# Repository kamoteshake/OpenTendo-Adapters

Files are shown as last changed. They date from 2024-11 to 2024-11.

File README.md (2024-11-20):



# OpenTendo-Adapters
Some components of OpenTendo are already obsolete or NRND (Not Recommended for New Design). OpenTendo-Adapters is trying to solve this issue by using a modern equivalent of the OpenTendo components with different footprints and adapting it OpenTendo.

> [!NOTE]
> If for some reason you can't find the components listed in the BOMs and/or decided to find your own, I recommend looking at the `Datasheets` folder. I've included the datasheets of the components used in OEM NES. Look for components that are close to the original component from OEM NES spec wise and that fits on the footprint in the adapters (or you could always fork this and update your own adapter 😉).

## File Structure
```
.
├── <Reference> Adapter  # Contains all files for a specific adapter.
|   |                      "Reference" is based from OpenTendo (i.e. X2 Adapter).
|   ├── BOM              # Contains the bill of materials.
|   ├── Datasheets       # Contains the datasheets of component/s used in the OEM NES
|   |                      on the referenced footprint of OpenTendo.
|   ├── Gerber Files     # Contains The gerber files needed for fabrication.
|   └── KiCad            # Contains all files necessary to open the project in KiCad. 
```

## License
Licensed under the TAPR Open Hardware License ([www.tapr.org/OHL](www.tapr.org/OHL))

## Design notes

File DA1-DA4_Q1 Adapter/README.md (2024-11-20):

# DA1-DA4 Q1 Adapter
DAN601 and uPA64H have been obsolete for a while. It's been difficult to find diode arrays that are close to DAN601 and uPA64H specs wise. It is easier to build an array from multiple single diodes. Since 2SA937 (Q1 in OpenTendo) is close by the diode arrays and is also obsolete, I decided to just include it in this adapter with a newer component that is somewhat close to 2SA937 spec wise.

## Gerber Files
There are two files in [Gerber Files](./Gerber%20Files/):
1. Single Board - Only consist of just one board.
2. Panelized - Consist of multiple board to fit in a 100mm x 100mm board. The panel have 9 (3x3) adapters. It is panelized using mouse bites.

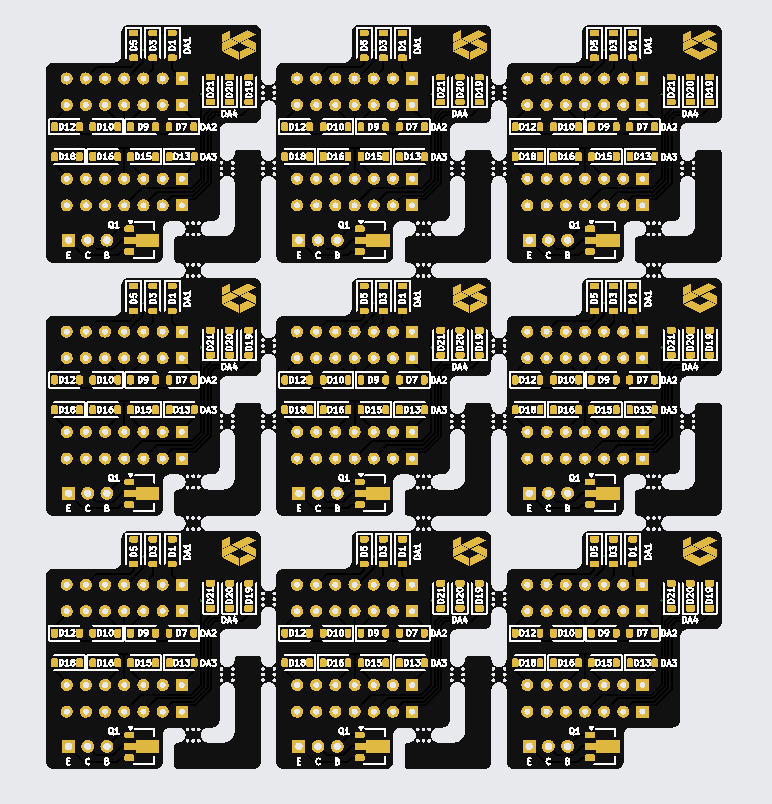
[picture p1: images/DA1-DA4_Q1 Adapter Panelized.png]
Panelized


## Assembly Tips
When soldering the pins, to make sure everything is lined up, put the pin through OpenTendo then put the adapter on the pins and tack some of the header pins before pulling it off from the OpenTendo. You can then finish soldering the pins on the adapter then you can solder the adapter to the OpenTendo.

## Images
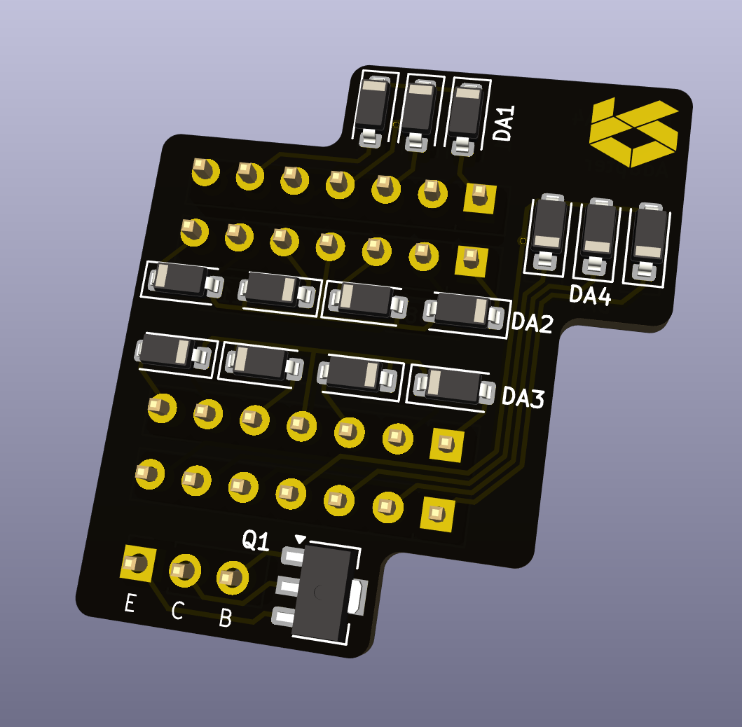
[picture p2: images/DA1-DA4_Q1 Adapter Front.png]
Front

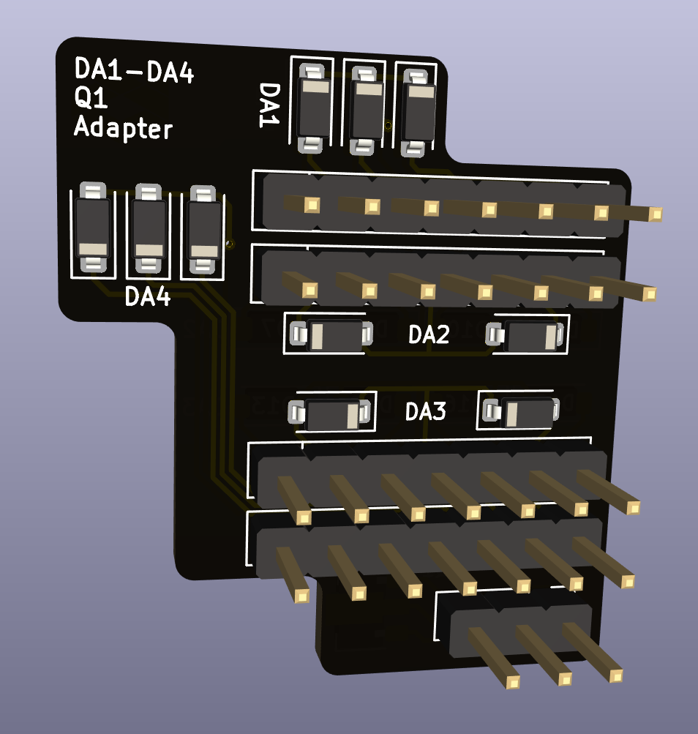
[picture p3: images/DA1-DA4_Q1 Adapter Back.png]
Back

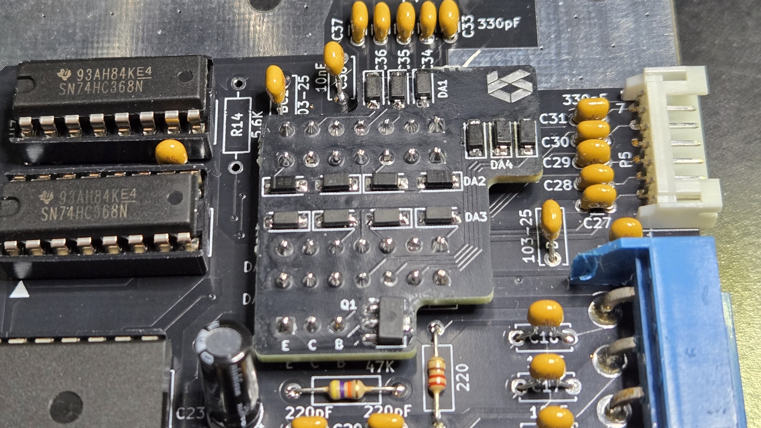
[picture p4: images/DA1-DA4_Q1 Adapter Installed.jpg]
Installed


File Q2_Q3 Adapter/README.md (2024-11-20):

# Q2 Q3 Adapter
This adapter replaces the 2SC2021 transistors. This transistor is used for the clock circuit. You might have to adjust the cap trimmer (TC1 in OpenTendo) to get a stable clock (21.47727MHz for NTSC and 26.601712MHz for PAL).

## Gerber Files
There are two files in [Gerber Files](./Gerber%20Files/):
1. Single Board - Only consist of just one board.
2. Panelized - Consist of multiple board to fit in a 100mm x 100mm board. The panel have 90 (10x9) adapters. It is panelized using mouse bites.

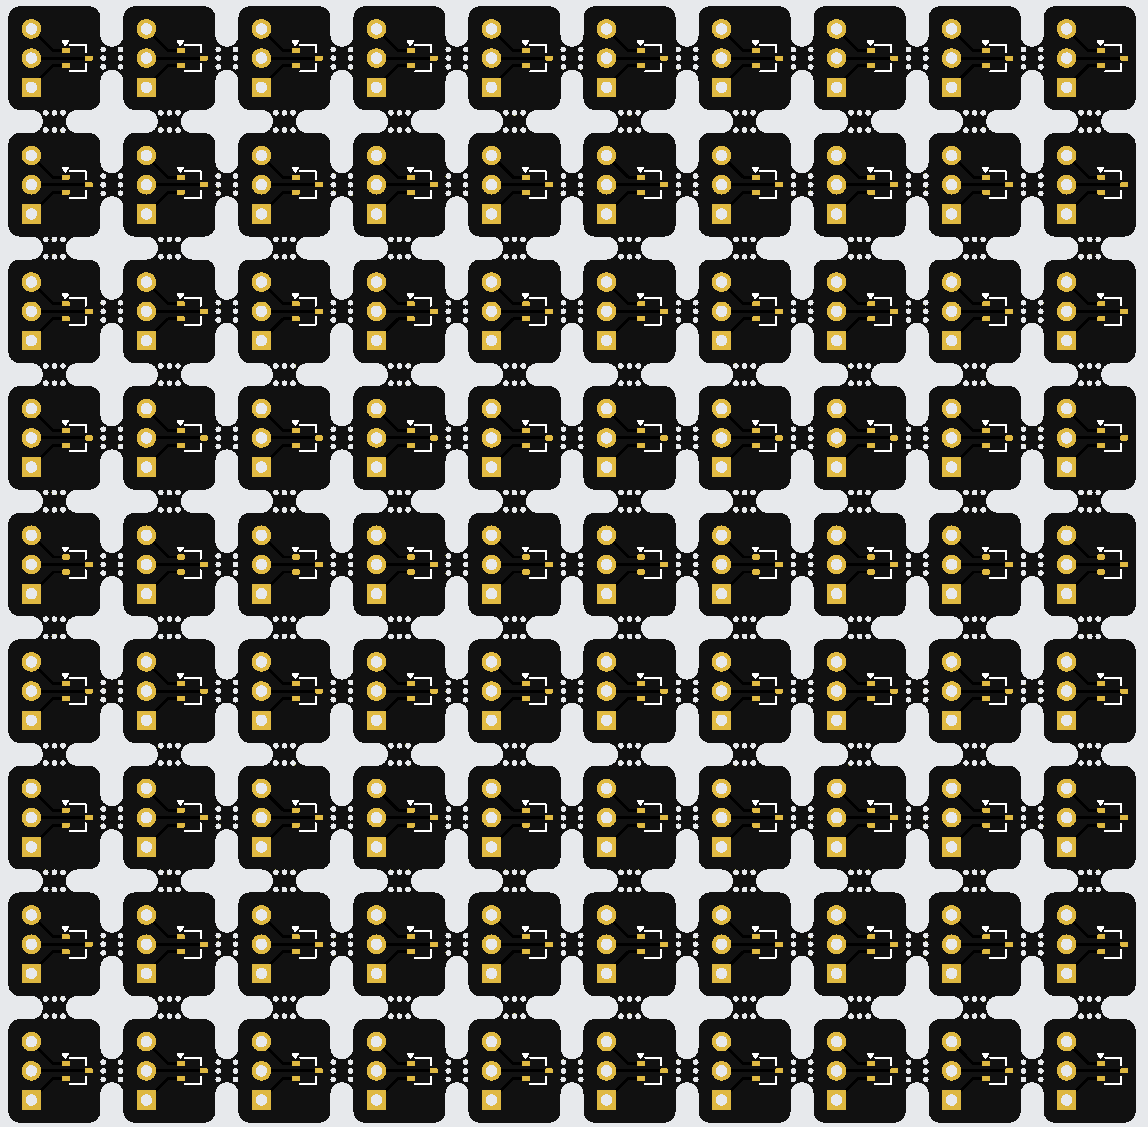
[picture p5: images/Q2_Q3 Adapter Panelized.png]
Panelized


## Assembly Tips
If you're using the right angle header pins, put the longer pins on the adapter side so you save a tiny bit of vertical space then you can just trim the pins off.

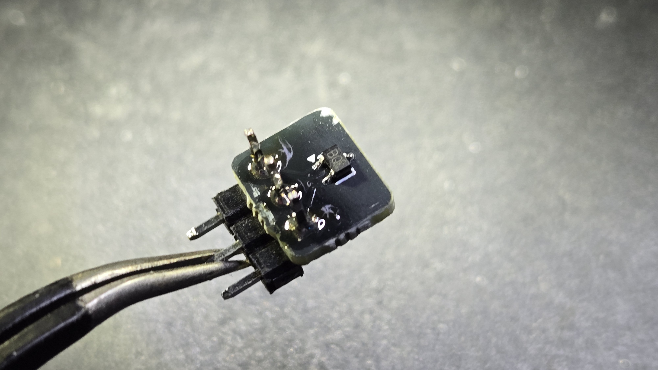
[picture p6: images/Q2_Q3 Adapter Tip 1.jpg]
Tip1

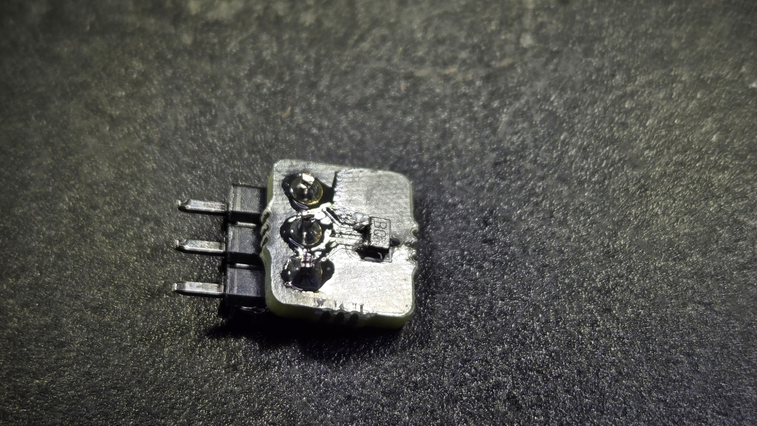
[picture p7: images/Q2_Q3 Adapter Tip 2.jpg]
Tip2


## Images
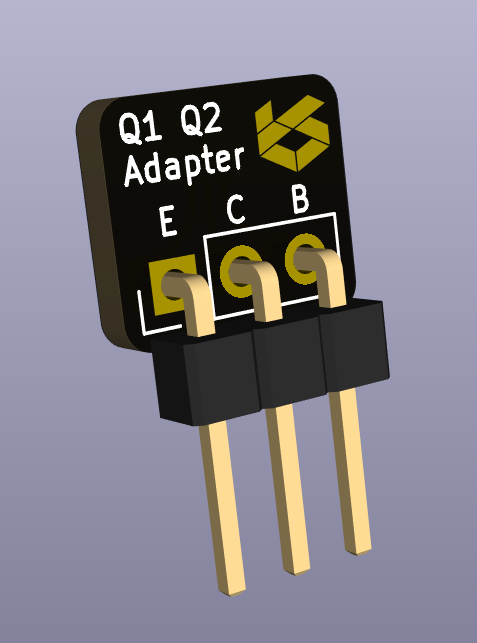
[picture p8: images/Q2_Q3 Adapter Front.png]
Front

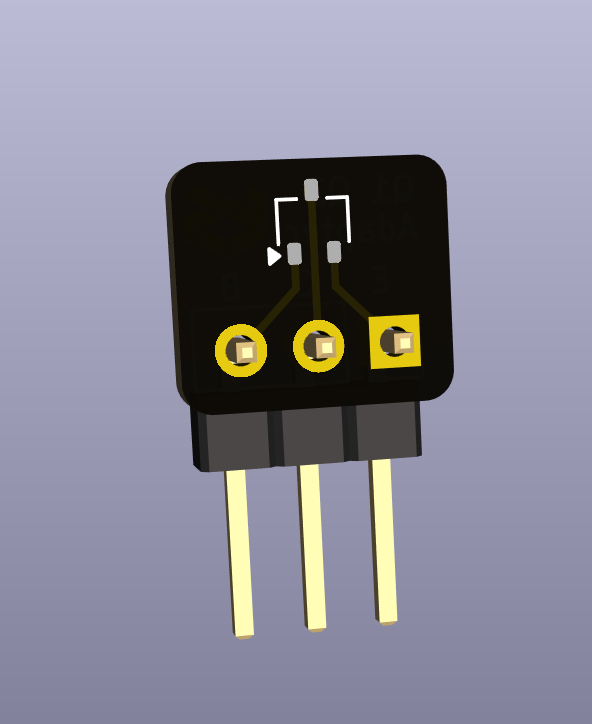
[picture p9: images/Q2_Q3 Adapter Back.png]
Back

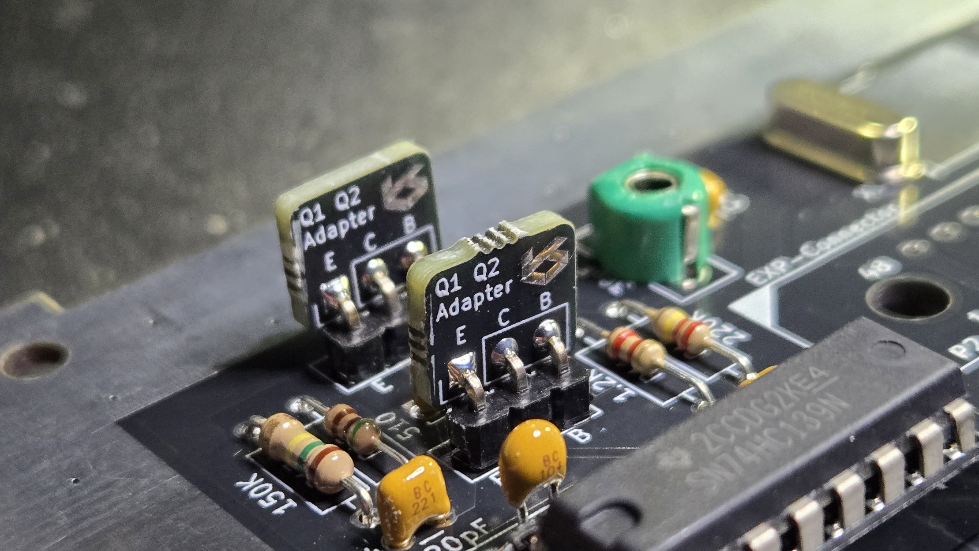
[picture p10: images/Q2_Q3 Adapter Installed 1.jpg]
Installed1

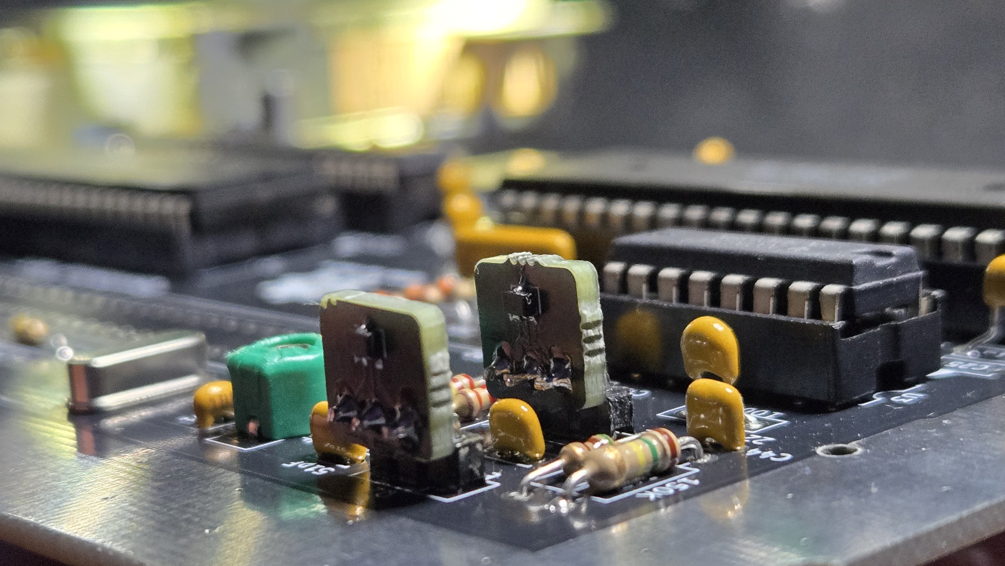
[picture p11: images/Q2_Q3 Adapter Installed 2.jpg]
Installed2


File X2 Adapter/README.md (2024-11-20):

# X2 Adapter
This adapter replaces the CSTLS4M00G56 ceramic resonator. I found CSTCR4M00G55B95 as a good replacement.

## Gerber Files
There are two files in [Gerber Files](./Gerber%20Files/):
1. Single Board - Only consist of just one board.
2. Panelized - Consist of multiple board to fit in a 100mm x 100mm board. The panel have 90 (10x9) adapters. It is panelized using mouse bites.

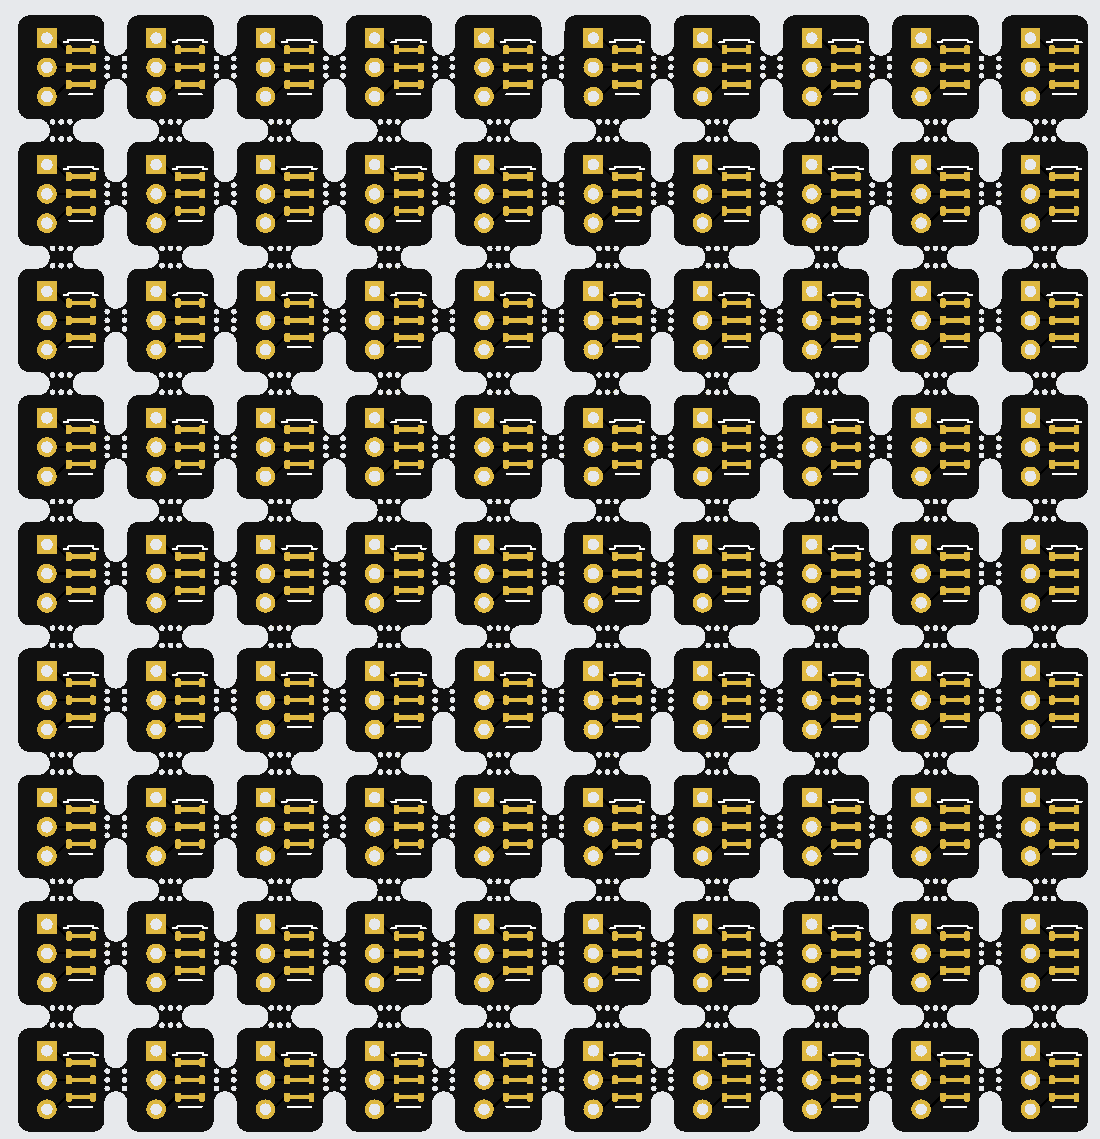
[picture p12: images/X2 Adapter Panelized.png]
Panelized


## Assembly Tips
If you're using the right angle header pins, put the longer pins on the adapter side so you save a tiny bit of vertical space then you can just trim the pins off.

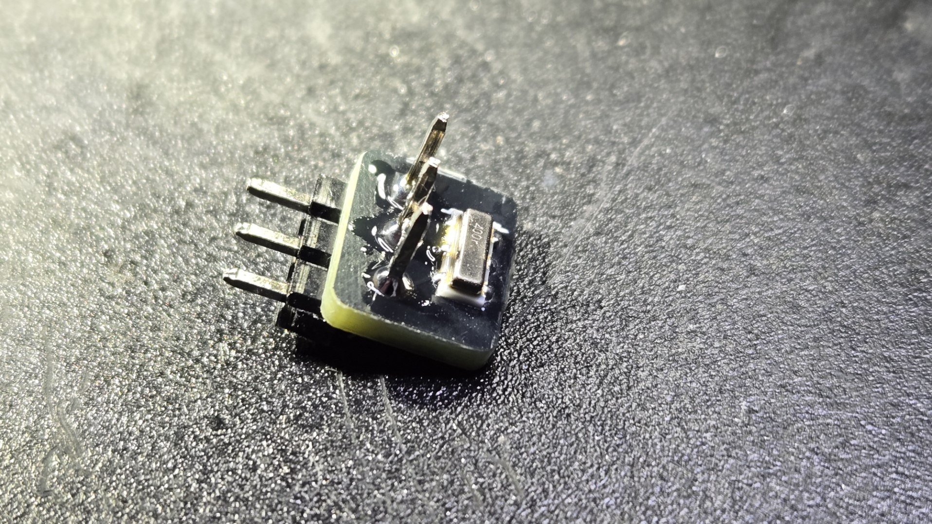
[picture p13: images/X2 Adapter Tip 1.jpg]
Tip1

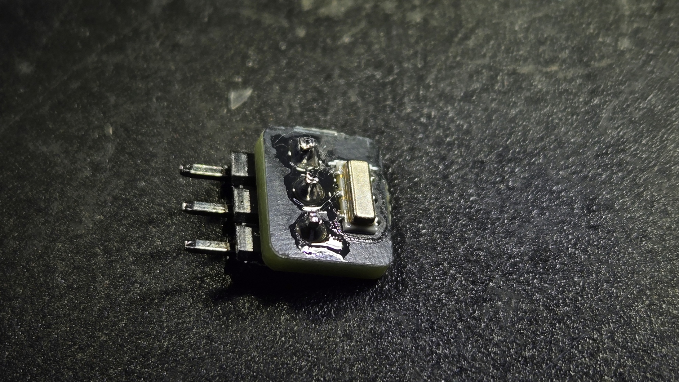
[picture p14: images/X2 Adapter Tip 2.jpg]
Tip2


## Images
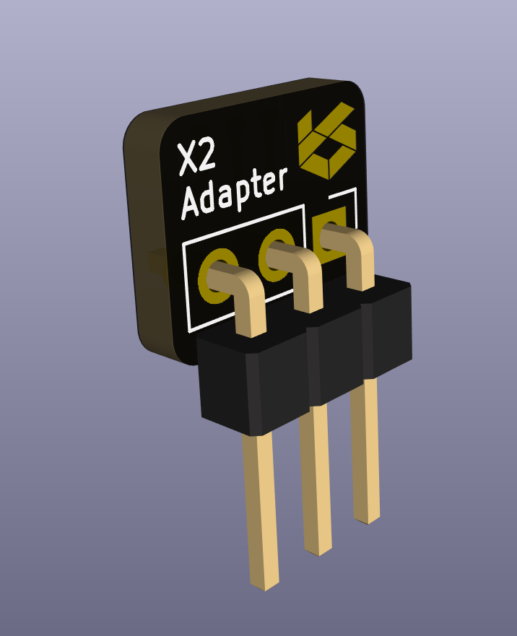
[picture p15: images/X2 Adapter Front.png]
Front

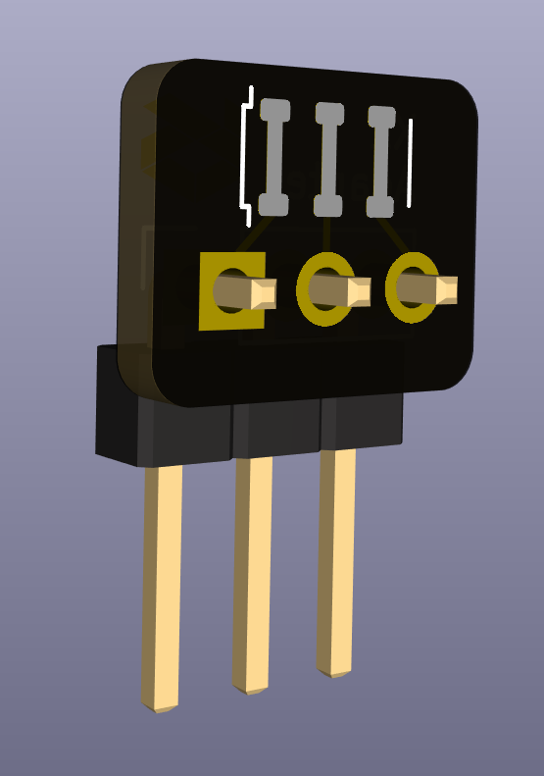
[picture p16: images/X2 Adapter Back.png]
Back

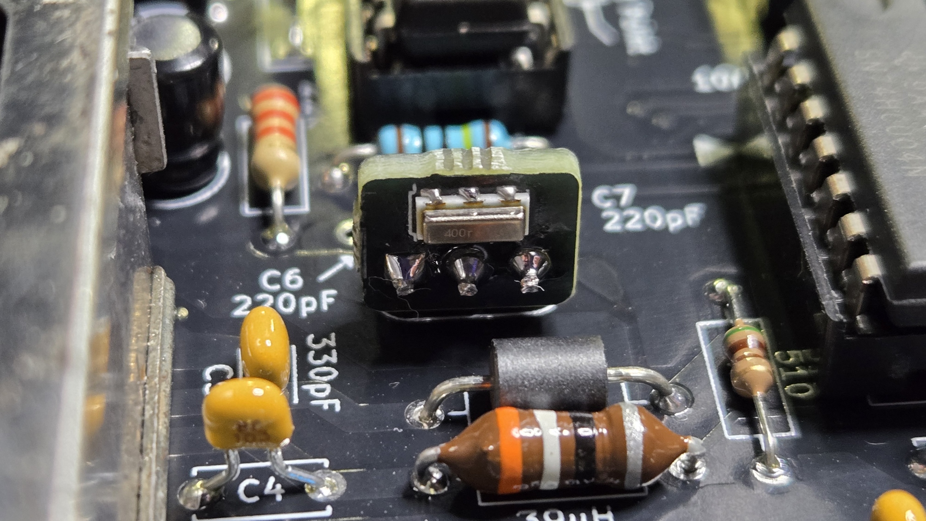
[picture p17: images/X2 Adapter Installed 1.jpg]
Installed1

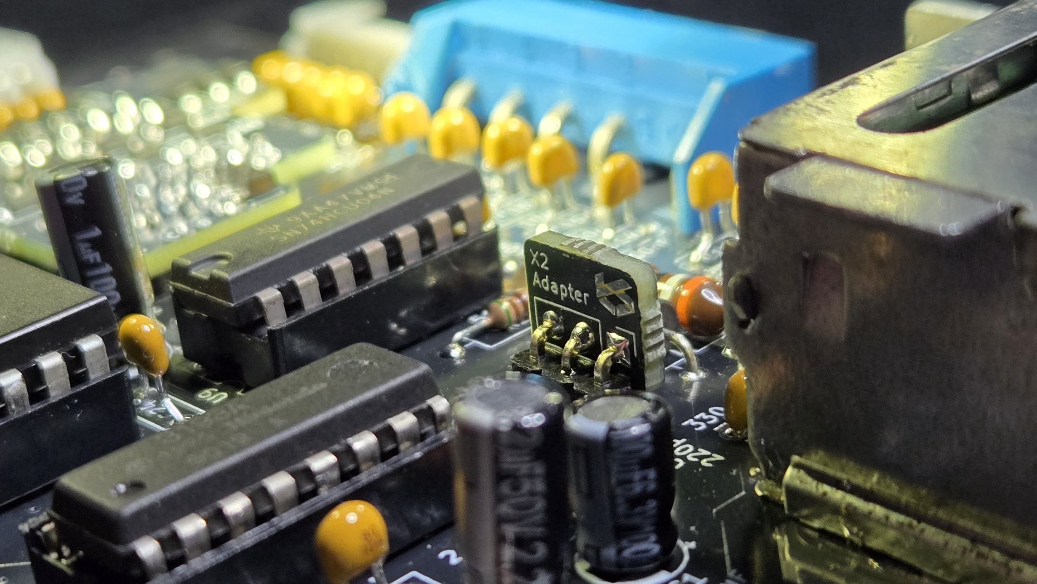
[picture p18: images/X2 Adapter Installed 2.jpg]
Installed2


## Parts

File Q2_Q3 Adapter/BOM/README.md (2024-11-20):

# Bill of Materials
Import the [bom.csv](./bom.csv) to [Octopart BOM Tool](https://octopart.com/my/bom-tool) or go [here](https://octopart.com/bom-tool/1uiU4qM6).

> [!IMPORTANT]
> The BOM only lists for 1 adapter, if you want to use the adapter for Q2 and Q3 on OpenTendo, you have to buy 2 of the transistors. Please read the note below about the header pins.

| Reference | Qty | Part | Description |
| --- | :-: | ---- | --- |
| Q1 | 1 | [2SC4081U3T106Q](https://octopart.com/2sc4081u3t106q-rohm-91418762) | NPN 50V 0.15A Bipolar Transistor SOT-323 SC-70 |
|  | 1 | [10129379-936001BLF](https://octopart.com/10129379-936001blf-amphenol+communications+solutions-126516413)<sup>[1]</sup> | 01x36 2.54mm Pitch Right Angle Header Pins |

> [!NOTE]
> <sup>[1]</sup> If you are making 2 adapters for Q2 and Q3 and/or the [X2 Adapter](../../X2%20Adapter/), you only need to buy one of the right angled header pins. 36 pins should be enough for the 3 small adapters.

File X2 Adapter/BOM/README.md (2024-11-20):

# Bill of Materials
Import the [bom.csv](./bom.csv) to [Octopart BOM Tool](https://octopart.com/my/bom-tool) or go [here](https://octopart.com/bom-tool/w1zb4VkG).

| Reference | Qty | Part | Description |
| --- | :-: | ---- | --- |
| Y1 | 1 | [CSTCR4M00G55B95-R0](https://octopart.com/cstcr4m00g55b95-r0-murata-21407080) | 4MHz Ceramic Resonator 39pF 45Ohms |
|  | 1 | [10129379-936001BLF](https://octopart.com/10129379-936001blf-amphenol+communications+solutions-126516413)<sup>[1]</sup> | 01x36 2.54mm Pitch Right Angle Header Pins |

> [!NOTE]
> <sup>[1]</sup> If you are also making [Q2_Q3 Adapter](../../Q2_Q3%20Adapter/), you only need to buy one of the right angled header pins. 36 pins should be enough for the 3 small adapters.

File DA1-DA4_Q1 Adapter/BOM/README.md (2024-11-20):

# Bill of Materials
Import the [bom.csv](./bom.csv) to [Octopart BOM Tool](https://octopart.com/my/bom-tool) or go [here](https://octopart.com/bom-tool/6hkiRDA8).

| Reference | Qty | Part | Description |
| --- | :-: | ---- | --- |
| D1, D2, D3,<br />D4, D5, D6,<br />D13, D14, D15,<br />D16, D17, D18 | 12 | [MBR0580S1-7](https://octopart.com/mbr0580s1-7-diodes+inc.-53081572) | 0.5A 80V Schottky Diode SOD-123 |
| D7, D8, D9,<br />D10, D11, D12,<br />D19, D20, D21,<br />D22, D23, D24 | 12 | [1N4150W-E3-18](https://octopart.com/1n4150w-e3-18-vishay-46456330) | 0.2A 50V Small Signal Switching Diode SOD-123 |
| Q1 | 1 | [2SA2071P5T100Q](https://octopart.com/2sa2071p5t100q-rohm-75515614) | PNP -60V -3A Bipolar Transistor SOT-89-3 |
|  | 1 | [10129378-936004BLF](https://octopart.com/10129378-936004blf-amphenol+communications+solutions-126516388) | 01x36 2.54mm Pitch Header Pins |

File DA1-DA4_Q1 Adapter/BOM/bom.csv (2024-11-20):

Query | Qty | Manufacturer | MPN | Octopart URL | Part Description | Description | Schematic Reference | Internal Part Number | Lifecycle | Lead Time | RoHS | Total Qty (@ Batch Size: 1) | SKU | SKU | SKU | SKU | SKU | Packaging | Packaging | Packaging | Packaging | Packaging | Unit Price (@ Batch Size: 1) | Unit Price (@ Batch Size: 1) | Unit Price (@ Batch Size: 1) | Unit Price (@ Batch Size: 1) | Unit Price (@ Batch Size: 1) | In Stock | In Stock | In Stock | In Stock | In Stock | MOQ | MOQ | MOQ | MOQ | MOQ | URL | URL | URL | URL | URL | Distributor [Lowest Price (Preferred Distributors)] | SKU [Lowest Price (Preferred Distributors)] | Packaging [Lowest Price (Preferred Distributors)] | Unit Price (@ Batch Size: 1) [Lowest Price (Preferred Distributors)] | Line Total [Lowest Price (Preferred Distributors)] | Batch Total [Lowest Price (Preferred Distributors)] | In Stock [Lowest Price (Preferred Distributors)] | MOQ [Lowest Price (Preferred Distributors)] | URL [Lowest Price (Preferred Distributors)] | Notes
 |  |  |  |  |  |  |  |  |  |  |  |  | Digi-Key | Mouser | Newark | Onlinecomponents.com | RS Components | Digi-Key | Mouser | Newark | Onlinecomponents.com | RS Components | Digi-Key | Mouser | Newark | Onlinecomponents.com | RS Components | Digi-Key | Mouser | Newark | Onlinecomponents.com | RS Components | Digi-Key | Mouser | Newark | Onlinecomponents.com | RS Components | Digi-Key | Mouser | Newark | Onlinecomponents.com | RS Components
MBR0580S1-7 | 12 | Diodes Inc. | MBR0580S1-7 | https://octopart.com/mbr0580s1-7-diodes+inc.-53081572 | Rectifier Diode, Schottky, 1 Phase, 1 Element, 0.5A, 80V V(RRM), Silicon |  | D1, D2, D3, D4, D5, D6. D13, D14, D15, D16, D17, D18 |  |  | 8w | Compliant | 12 | MBR0580S1-7DICT-ND | 621-MBR0580S1-7 | 07AH4105 |  |  | Cut Tape | Tape & Reel | Cut Tape |  |  | 0.11 | 0.11 | 0.037 |  |  | 72952 | 30320 | 8872 |  |  | 1 | 1 | 1 |  |  | https://octopart.com/opatz8j6/a1 | https://octopart.com/opatz8j6/a1 | https://octopart.com/opatz8j6/a1 |  |  | Newark | 07AH4105 | Cut Tape | 0.037 | 0.44399999999999995 | 0.44399999999999995 | 8872 | 1 | https://octopart.com/opatz8j6/a1
1N4150W-E3-18 | 12 | Vishay | 1N4150W-E3-18 | https://octopart.com/1n4150w-e3-18-vishay-46456330 | Rectifier Diode Small Signal Switching Si 50V 0.2A 4ns 2-Pin SOD-123 T/R |  | D7, D8, D9, D10, D11, D12, D19, D20, D21, D22, D23, D24 |  |  | 13w | Compliant | 12 | 1N4150W-E3-18GICT-ND | 78-1N4150W-E3-18 | 09X6132 |  |  | Cut Tape | Tape & Reel | Tape & Reel |  |  | 0.101 | 0.101 |  |  |  | 40651 | 25705 | 0 |  |  | 1 | 1 | 10000 |  |  | https://octopart.com/opatz8j6/a1 | https://octopart.com/opatz8j6/a1 | https://octopart.com/opatz8j6/a1 |  |  | DigiKey | 1N4150W-E3-18GICT-ND | Cut Tape | 0.101 | 1.2120000000000002 | 1.2120000000000002 | 40651 | 1 | https://octopart.com/opatz8j6/a1
2SA2071P5T100Q | 1 | ROHM | 2SA2071P5T100Q | https://octopart.com/2sa2071p5t100q-rohm-75515614 | Bipolar Transistors - BJT PNP -3A Ic -60V Vceo MPT3 |  | Q1 |  |  | 13w | Compliant | 1 | 2SA2071P5T100QCT-ND | 755-2SA2071P5T100Q |  |  |  | Cut Tape | Tape & Reel |  |  |  | 0.91 | 0.73 |  |  |  | 2036 | 3898 |  |  |  | 1 | 1 |  |  |  | https://octopart.com/opatz8j6/a1 | https://octopart.com/opatz8j6/a1 |  |  |  | Mouser | 755-2SA2071P5T100Q | Tape & Reel | 0.73 | 0.73 | 0.73 | 3898 | 1 | https://octopart.com/opatz8j6/a1
10129378-936004BLF | 1 | Amphenol Communications Solutions | 10129378-936004BLF | https://octopart.com/10129378-936004blf-amphenol+communications+solutions-126516388 | Header Sr Vt Th 1X36-10129378-936004BLF | Amphenol Fci (amphenol Cs) 10129378936004BLF | Header pins |  |  |  | 10w |  | 1 | 10129378-936004BLF-ND | 649-1012937893604BLF | 45AC1146 | 10129378-936004BLF |  | Bulk | Bulk |  | Bulk |  | 0.62 | 0.65 | 0.257 |  |  | 4802 | 4678 | 279 | 1400 |  | 1 | 1 | 1 | 100 |  | https://octopart.com/opatz8j6/a1 | https://octopart.com/opatz8j6/a1 | https://octopart.com/opatz8j6/a1 | https://octopart.com/opatz8j6/a1 |  | Newark | 45AC1146 |  | 0.257 | 0.257 | 0.257 | 279 | 1 | https://octopart.com/opatz8j6/a1

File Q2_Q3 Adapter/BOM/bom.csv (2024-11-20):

Query | Qty | Manufacturer | MPN | Octopart URL | Part Description | Description | Schematic Reference | Internal Part Number | Lifecycle | Lead Time | RoHS | Total Qty (@ Batch Size: 1) | SKU | SKU | SKU | SKU | SKU | Packaging | Packaging | Packaging | Packaging | Packaging | Unit Price (@ Batch Size: 1) | Unit Price (@ Batch Size: 1) | Unit Price (@ Batch Size: 1) | Unit Price (@ Batch Size: 1) | Unit Price (@ Batch Size: 1) | In Stock | In Stock | In Stock | In Stock | In Stock | MOQ | MOQ | MOQ | MOQ | MOQ | URL | URL | URL | URL | URL | Distributor [Lowest Price (Preferred Distributors)] | SKU [Lowest Price (Preferred Distributors)] | Packaging [Lowest Price (Preferred Distributors)] | Unit Price (@ Batch Size: 1) [Lowest Price (Preferred Distributors)] | Line Total [Lowest Price (Preferred Distributors)] | Batch Total [Lowest Price (Preferred Distributors)] | In Stock [Lowest Price (Preferred Distributors)] | MOQ [Lowest Price (Preferred Distributors)] | URL [Lowest Price (Preferred Distributors)] | Notes
 |  |  |  |  |  |  |  |  |  |  |  |  | Digi-Key | Mouser | Newark | Onlinecomponents.com | RS Components | Digi-Key | Mouser | Newark | Onlinecomponents.com | RS Components | Digi-Key | Mouser | Newark | Onlinecomponents.com | RS Components | Digi-Key | Mouser | Newark | Onlinecomponents.com | RS Components | Digi-Key | Mouser | Newark | Onlinecomponents.com | RS Components | Digi-Key | Mouser | Newark | Onlinecomponents.com | RS Components
2SC4081U3T106Q | 1 | ROHM | 2SC4081U3T106Q | https://octopart.com/2sc4081u3t106q-rohm-91418762 | Tape & Reel (TR) Surface Mount NPN EAR99 Bipolar (BJT) Transistor 120 @ 1mA 6V 150mA 200mW 180MHz |  | Q1 |  |  | 18w |  | 1 | 2SC4081U3T106QCT-ND | 755-2SC4081U3T106Q |  |  |  | Cut Tape | Tape & Reel |  |  |  | 0.21 | 0.17 |  |  |  | 155440 | 38153 |  |  |  | 1 | 1 |  |  |  | https://octopart.com/opatz8j6/a1 | https://octopart.com/opatz8j6/a1 |  |  |  | Mouser | 755-2SC4081U3T106Q | Tape & Reel | 0.17 | 0.17 | 0.17 | 38153 | 1 | https://octopart.com/opatz8j6/a1
10129379-936001BLF | 1 | Amphenol Communications Solutions | 10129379-936001BLF | https://octopart.com/10129379-936001blf-amphenol+communications+solutions-126516413 | Header Sr Ra Th 1X36-10129379-936001BLF | Amphenol Fci (amphenol Cs) 10129379936001BLF |  |  |  |  | 10w |  | 1 | 10129379-936001BLF-ND | 649-1012937993601BLF | 45AC1196 | 10129379-936001BLF |  | Bulk | Bulk |  | Bulk |  | 0.76 | 0.71 | 0.116 |  |  | 3897 | 836 | 2573 | 6400 |  | 1 | 1 | 1 | 100 |  | https://octopart.com/opatz8j6/a1 | https://octopart.com/opatz8j6/a1 | https://octopart.com/opatz8j6/a1 | https://octopart.com/opatz8j6/a1 |  | Newark | 45AC1196 |  | 0.116 | 0.116 | 0.116 | 2573 | 1 | https://octopart.com/opatz8j6/a1

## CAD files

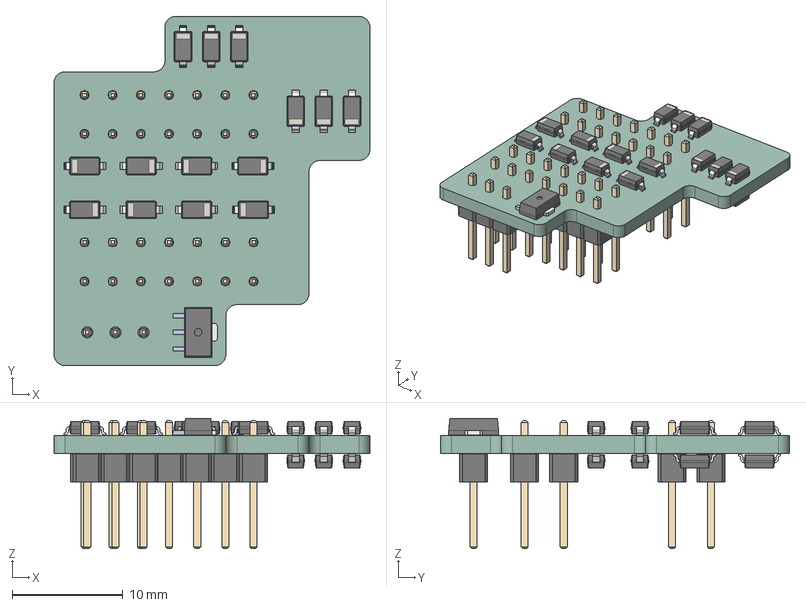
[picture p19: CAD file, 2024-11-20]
DA1-DA4_Q1 Adapter/KiCad/DA1-DA4_Q1 Adapter.step
28.5 x 31.5 x 11.8 mm
D_SOD_123 x 24
CQ assembly
PinHeader_1x07_P254mm_Vertical x 4
PinHeader_1x03_P254mm_Vertical
DAN601 And uPA64H Adapter_PCB

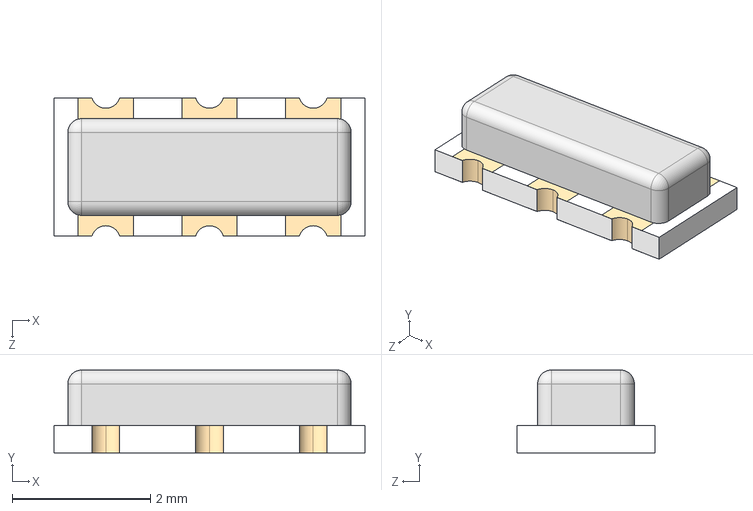
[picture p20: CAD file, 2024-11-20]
X2 Adapter/KiCad/3D Model/CSTCR4M00G55B95-R0.step
4.50 x 1.20 x 2.00 mm

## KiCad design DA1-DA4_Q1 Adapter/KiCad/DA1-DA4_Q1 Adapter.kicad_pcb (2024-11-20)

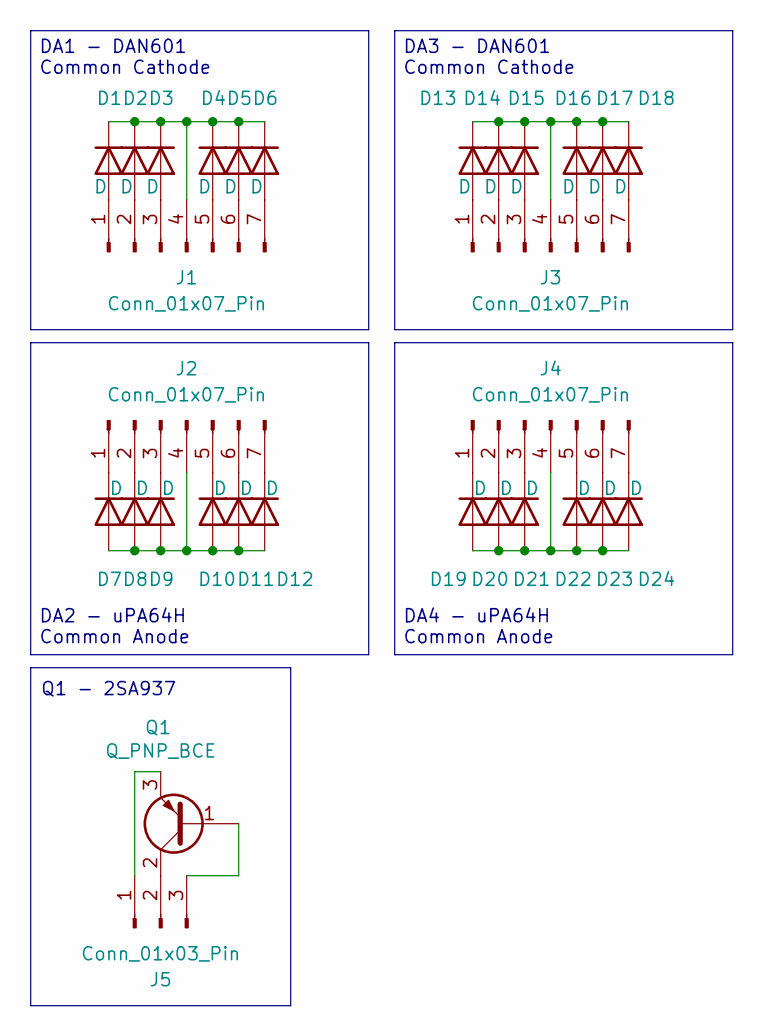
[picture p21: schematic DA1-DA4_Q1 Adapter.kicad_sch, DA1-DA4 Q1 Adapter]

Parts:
D1, D2, D3, D4, D5, D6, D7, D8, D9, D10, D11, D12, D13, D14, D15, D16, D17, D18, D19, D20, D21, D22, D23, D24: D; D_SOD-123
J1, J2, J3, J4: Conn_01x07_Pin; R_Array_SIP7
J5: Conn_01x03_Pin; PinHeader_1x03_P2.54mm_Vertical
Q1: Q_PNP_BCE; SOT-89-3

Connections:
unnamed: D1.2 (A), J1.1
unnamed: D1.1 (K), D2.1 (K), D3.1 (K), D4.1 (K), D5.1 (K), D6.1 (K), J1.4
unnamed: D2.2 (A), J1.2
unnamed: D3.2 (A), J1.3
unnamed: D4.2 (A), J1.5
unnamed: D5.2 (A), J1.6
unnamed: D6.2 (A), J1.7
unnamed: D7.1 (K), J2.1
unnamed: D8.1 (K), J2.2
unnamed: D9.1 (K), J2.3
unnamed: D7.2 (A), D8.2 (A), D9.2 (A), D10.2 (A), D11.2 (A), D12.2 (A), J2.4
unnamed: D10.1 (K), J2.5
unnamed: D11.1 (K), J2.6
unnamed: D12.1 (K), J2.7
unnamed: D13.2 (A), J3.1
unnamed: D13.1 (K), D14.1 (K), D15.1 (K), D16.1 (K), D17.1 (K), D18.1 (K), J3.4
unnamed: D14.2 (A), J3.2
unnamed: D15.2 (A), J3.3
unnamed: D16.2 (A), J3.5
unnamed: D17.2 (A), J3.6
unnamed: D18.2 (A), J3.7
unnamed: D19.2 (A), D20.2 (A), D21.2 (A), D22.2 (A), D23.2 (A), D24.2 (A), J4.4
unnamed: D19.1 (K), J4.1
unnamed: D20.1 (K), J4.2
unnamed: D21.1 (K), J4.3
unnamed: D22.1 (K), J4.5
unnamed: D23.1 (K), J4.6
unnamed: D24.1 (K), J4.7
unnamed: J5.1, Q1.3 (E)
unnamed: J5.2, Q1.2 (C)
unnamed: J5.3, Q1.1 (B)

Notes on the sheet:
DA1 - DAN601 Common Cathode
DA4 - uPA64H Common Anode
DA2 - uPA64H Common Anode
Q1 - 2SA937
DA3 - DAN601 Common Cathode

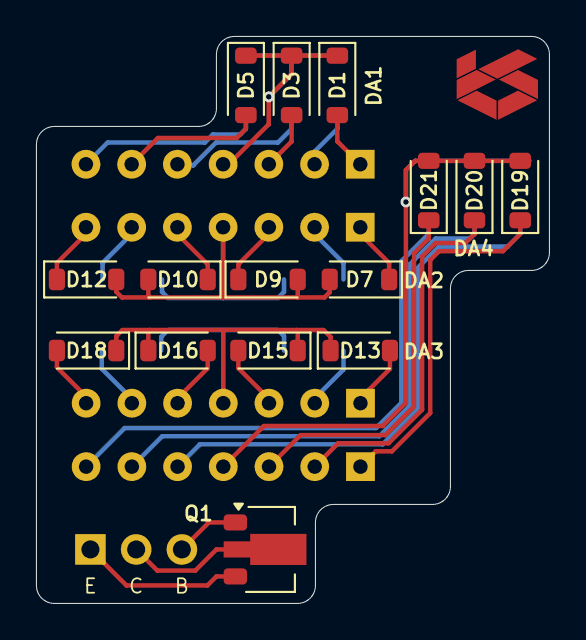
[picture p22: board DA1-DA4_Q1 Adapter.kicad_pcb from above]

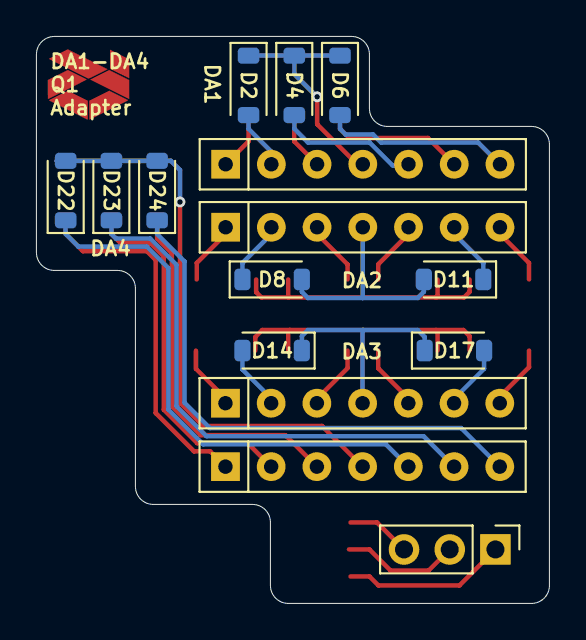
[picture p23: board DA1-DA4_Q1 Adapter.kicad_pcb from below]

Board: 2 copper layers, 28.5 x 31.5 mm, 30 parts (15 on the bottom side), 31 nets.

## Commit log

2024-11-20 feat: initial commit
    [CSTCR4M00G55B95-R0.step, DA1-DA4_Q1 Adapter.kicad_pcb, DA1-DA4_Q1 Adapter.kicad_sch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]
2024-11-20 fix: BOM readme
2024-11-20 feat: added kicad version
